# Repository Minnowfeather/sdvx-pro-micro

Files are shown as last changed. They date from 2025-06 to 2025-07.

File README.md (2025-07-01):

# DJDao Arduino Drop-in Replacement

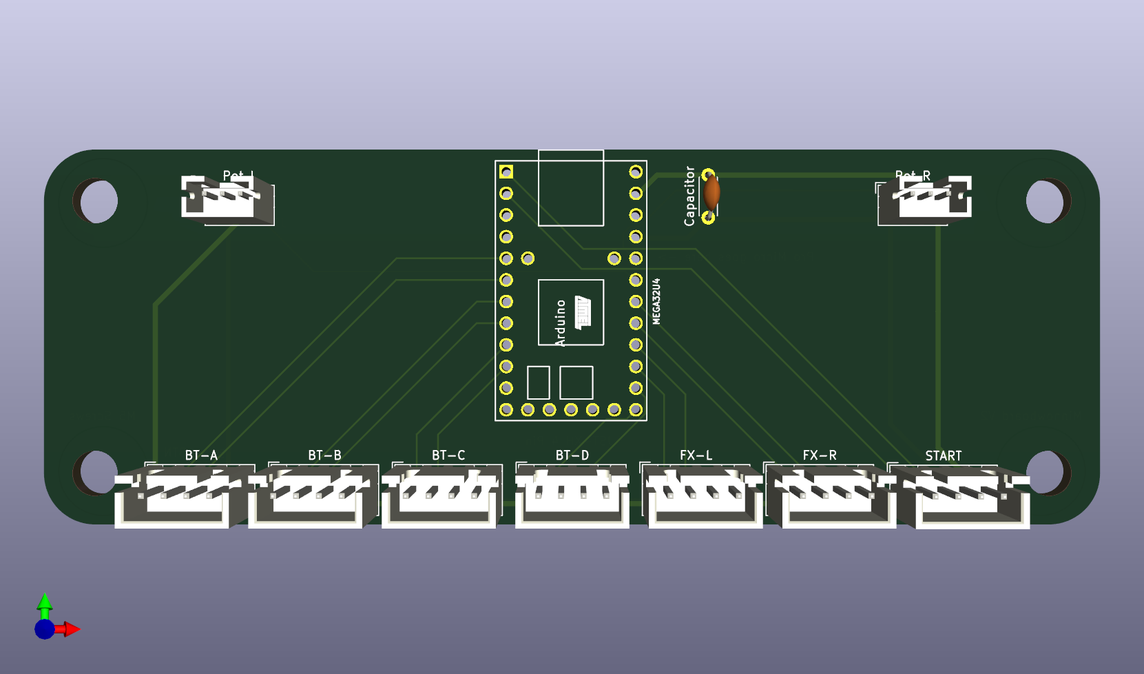
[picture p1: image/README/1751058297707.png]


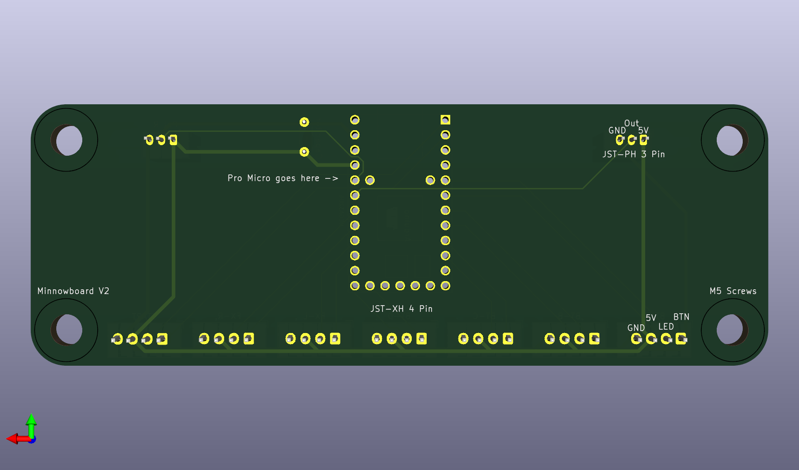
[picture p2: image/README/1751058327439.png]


This project aims to be a drop-in replacement for DJDao SVSE5 and SVRE9 PCBs. Currently only supports potentiometers and DJDao-style wiring.

LEDs are wired to 5V and a GPIO pin on the Pro Micro. Writing LOW will turn ON the LED, and writing HIGH will turn it OFF. If your LEDs don't turn on, try flipping them around.

# Pin assignments

| Button | Data | LED |
| --- | ---- | --- |
| BT-A | 2 | 3 |
| BT-B | 4 | 5 |
| BT-C | 6 | 7 |
| BT-D | 10 | 16  |
| FX-L | 14 | 15  |
| FX-R | A0 | A1  |
| Start  | 1 | 0 |
| VOL-L  | A2 | N/A |
| VOL-R  | A3 | N/A |

# Code

Use a modifed version of [KnucklesLee&#39;s code](https://github.com/knuckleslee/RhythmCodes/).

# Known Issues

V1: Pots are jittery, affected by the LEDs, and each other(?)
V1: Button pins have swapped GND and 5V

V2: Pots are a bit jittery when using a 0.1μF capacitor. Possibly fixed with higher value cap?
V2: Pro Micro footprint is actually a Teensy 2.0 footprint. This is only a cosmetic difference.
V2: Pro Micro USB-C slot is blocked by the Start button, requiring it to be mounted upside-down
V2: Upside-down mounting might require extension cables for each button

# ToDO

- Add pins for a reset button
- Replace Teensy footprint with Pro Micro footprint
- Add quadrature encoder support
- Add firmware code

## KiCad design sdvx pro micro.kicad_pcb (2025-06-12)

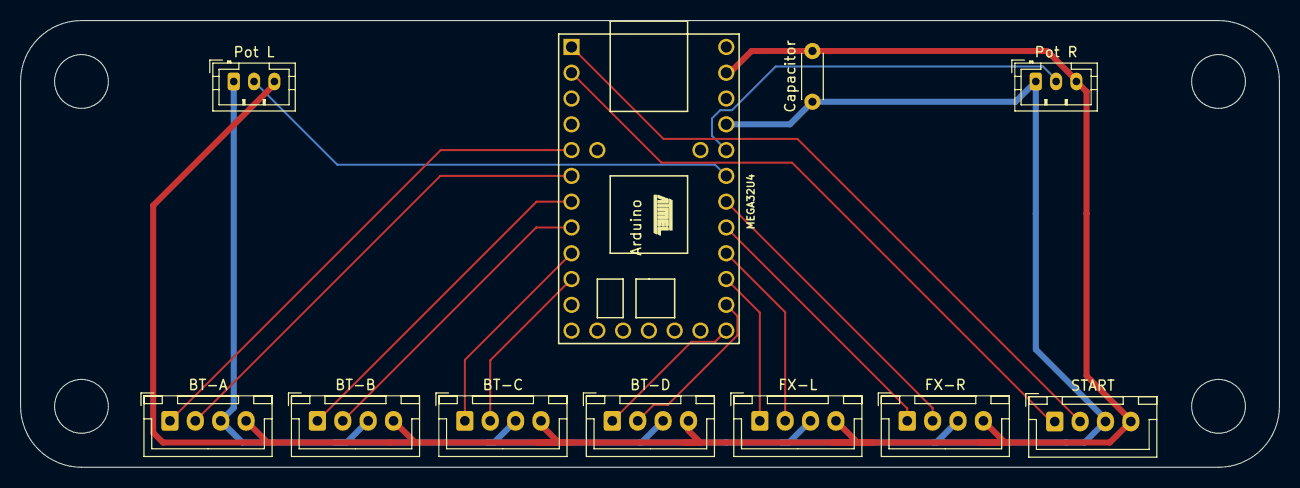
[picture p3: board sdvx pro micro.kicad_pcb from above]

Board: 2 copper layers, 124.0 x 44.0 mm, 11 parts (0 on the bottom side), 5 nets.

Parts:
Arduino: Teensy2.0
BT-A: JST_XH_B4B-XH-A_1x04_P2.50mm_Vertical
BT-B: JST_XH_B4B-XH-A_1x04_P2.50mm_Vertical
BT-C: JST_XH_B4B-XH-A_1x04_P2.50mm_Vertical
BT-D: JST_XH_B4B-XH-A_1x04_P2.50mm_Vertical
Capacitor: C_Disc_D4.3mm_W1.9mm_P5.00mm
FX-L: JST_XH_B4B-XH-A_1x04_P2.50mm_Vertical
FX-R: JST_XH_B4B-XH-A_1x04_P2.50mm_Vertical
Pot L: JST_PH_B3B-PH-K_1x03_P2.00mm_Vertical
Pot R: JST_PH_B3B-PH-K_1x03_P2.00mm_Vertical
START: JST_XH_B4B-XH-A_1x04_P2.50mm_Vertical

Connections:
5V: Arduino.26, BT-A.3, BT-B.3, BT-C.3, BT-D.3, Capacitor.1, FX-L.3, FX-R.3, Pot L.1, Pot R.1, START.3
ButtonData: Arduino.2, Arduino.5, Arduino.7, Arduino.9, Arduino.18, Arduino.20, Arduino.22, BT-A.1, BT-B.1, BT-C.1, BT-D.1, FX-L.1, FX-R.1, START.1
EncData: Arduino.24, Arduino.25, Pot L.2, Pot R.2
Ground: Arduino.3, Arduino.4, Arduino.28, BT-A.4, BT-B.4, BT-C.4, BT-D.4, Capacitor.2, FX-L.4, FX-R.4, Pot L.3, Pot R.3, START.4
LightData: Arduino.1, Arduino.6, Arduino.8, Arduino.10, Arduino.19, Arduino.21, Arduino.23, BT-A.2, BT-B.2, BT-C.2, BT-D.2, FX-L.2, FX-R.2, START.2

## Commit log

2025-06-08 V1 upload
    [sdvx pro micro.kicad_pcb, sdvx pro micro.kicad_sch]
2025-06-12 added capacitor to 5V line to reduce capacitor noise. swapped JST-ZH for JST-PH
    [sdvx pro micro.kicad_pcb]
2025-06-12 swapped JST-ZH for PH, added capacitor to stabilize pots
2025-06-12 Increased GND track width, moved capacitor closer to VCC
    [sdvx pro micro.kicad_pcb]
